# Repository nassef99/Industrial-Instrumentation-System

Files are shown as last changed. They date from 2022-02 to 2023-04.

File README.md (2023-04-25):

# Industrial_Instrumentation_System
ECEN 403/404 Team 45's Senior Design Project (Fall 2021-Spring 2022)

Folders are organized by subsytem/componenents of the overall project.

# NOTE
This repository was cloned from a GitHub Enterprise instance belonging to Texas A&M University, in order to preserve the code before it is shut down. This code was not copied or altered, and authorship belongs to Nassef Ameen, Mitchell Taylor, Ross Petersen, and Julio Gonzalez for their contributions to the original repository.

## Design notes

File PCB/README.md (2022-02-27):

# Altium/PCB Files

Link to original repository: https://github.tamu.edu/mitchtay20/AltiumProject

These are all of the files used to create our 6-layer PCB design in Altium.

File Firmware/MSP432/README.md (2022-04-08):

# Firmware
Firmware for both the MSP432 and ESP32 is found here:

The MSP432 is the microcontroller unit used for this project. It is used to communicate to the sensors/analog to digital converters,
as well as an electronic paper display.

The ESP32 Wifi Module is used to connect the microcontroller unit as well as the cloud databse to facilitate the transfer of data between them. From there this data
can be published to the web application.

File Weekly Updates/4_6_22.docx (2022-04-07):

Julio Gonzalez

- Accomplishments
  - Started Soldering the PCB
- Ongoing Progress
  - Need to figure out how to solder 01005 component onto board
  - Finish integration (soldering) and troubleshoot PCB

Mitchell Taylor

- Accomplishments
  - Finished UART port code
- Ongoing Progress
  - Finish analog to digital code

Nassef Ameen

- Accomplishments
  - Electronic Paper Display code is integrated with rest of firmware
- Ongoing Progress
  - Working on finishing MCU firmware w/Mitchell
  - Helping with ESP32 integration to database (Ross)

Ross Petersen

- Accomplishments
  - Created a serial connection for the ESP32
- Ongoing Progress
  - Finishing ESP32 firmware

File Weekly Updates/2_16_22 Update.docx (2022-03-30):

Julio Gonzalez

- Accomplishment
  - Replaced components that didn’t meet specifications
- Ongoing
  - Order all the parts to populate the PCB
  - Send PCB files for manufacturing

Mitchell Taylor

- Accomplishments
  - Rerouted new components needed for replacement
  - Redid the naming convention for the parts
- Ongoing Progress
  - Getting code done forf MCU

Nassef Ameen

- Accomplishments
  - No progress made on subsystem while PCB design is finalized and order is placed.
- Ongoing Progress
  - Starting code for MSP432 w/Mitchell in preparation for receiving board.
  - Also assisting with code for ESP32 to test integration with wifi module to database

Ross Petersen

- Accomplishments
  - Fixed power routing
  - Figured out what was causing most PCB errors
  - Picked up esp32 test board to test code
- Ongoing Progress
  - Work on esp32 code
  - Finish adding final components to PCB
  - Order PCB

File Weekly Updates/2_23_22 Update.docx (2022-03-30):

Julio Gonzalez

- Accomplishment
  - No major accomplishments personally
  - Sent PCB files to manufacturer (Mitchell)
- Ongoing
  - Purchase all components to populate PCB

Mitchell Taylor

- Accomplishments
  - Got all design files to manufacturer and got feedback from them.
- Ongoing Progress
  - Fixing issues that put the PCB on hold as well as write code skeleton.

Nassef Ameen

- Accomplishments
  - No major accomplishments, planning to make substantial progress by the end of the week
- Ongoing Progress
  - Looking at code for ESP32, as well as MSP432 for Wifi module to database and Microcontroller Unit to database/e-paper display.

Ross Petersen

- Accomplishments
  - Board ordered, fixed manufacturer specifications
- Ongoing Progress
  - Working on esp32 code
  - Plan to test code

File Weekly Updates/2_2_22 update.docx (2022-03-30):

Julio Gonzalez:

- Accomplishments:
  - Finalized Dual Flow Meter schematic on Altium
  - Troubleshooted Flow Meter circuit and obtained a proper pulse output
- Current Goals:
- Finalize 24V Converter schematic
- Integrate Flow Meter and 24V Converter to overall PCB design

Mitchell Taylor:

- Accomplishment:
  - Re-routed MCU, Duel Flow meter, ect.
  - Updated schematics for clarity
  - Condensed the PCB components significantly
  - Connected all individual sub systems together on PCB
- Current Goals:
  - Finalize the design
  - Get github working
  - Get the PCB ordered

Nassef Ameen

- Accomplishments this past week:
  - Set up Altium to help oversee final PCB design changes
  - Helped set up project GitHub repository for project files
- Current Goals:
  - Help finish PCB design so we can order ASAP
  - Get ready to code MCU/E-paper display while board is coming in

Ross Petersen

- Accomplishments
  - Created and presented firstbi-weekly status update
  - Confirmed web interface still connects with database
  - Set up github for PCB files
- Current Goals
  - Add all PCB files to github
  - Finish routing ground and power in PCB design
  - Validate PCB design
  - Order PCB
  - Start preparing code for ESP32

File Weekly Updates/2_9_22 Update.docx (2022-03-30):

Julio Gonzalez:

- Accomplishments:
  - Completed 24V converter schematic
  - Integrated flowmeter and 24V converter schematics (with help of Ross)
- Current Goals:
  - Go through and review the components, swap out components.
  - Order parts for soldering the PCB

Mitchell Taylor:

- Accomplishments:
  - Finished up some routing on PCB, set up git hub for clarity.
- Current Goals:
  - Work on code for MCU and communicate to manufacturers.

Nassef Ameen

- Accomplishments:
  - Helped finish PCB design, double checking routine and component connections and troubleshooting errors
- Current Goals:
  - Prepare to code MCU, and look into that as well as integrating e-paper display
  - Look into testing integration with the database and MCU/ESP32

Ross Petersen

- Accomplishments:
  - Routed all power and ground nets on PCB
  - Finished routing all Flowmeter and MCU nets
  - Completely implemented and routed 24V Converter on PCB
- Current Goals:
  - Order PCB
  - Start coding for ESP32

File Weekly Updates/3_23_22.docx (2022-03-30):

Julio Gonzalez

- Accomplishments
  - Replaced a header footprint on Altium PCB Design with Ross
  - Obtained all PCB parts in-hand
- Ongoing Progress
  - Will pick up 4-20mA simulators from lusher today
  - Waiting for PCB to arrive (ETA Tuesday)

Mitchell Taylor

- Accomplishments
  - Worked on alanlog understanding
- Ongoing Progress
  - Working on MCU firmware

Nassef Ameen

- Accomplishments
  - Obtained examples on use of MSP432 Analog peripherals (eg. ADC14)
- Ongoing Progress
  - Working on MCU firmware

Ross Petersen

- Accomplishments
  - Fixed issues with manufacturer files (again)
  - Moved MCU to top layer, fixed footprint of headers and fixed their routing with Julio
- Ongoing Progress
  - Working on ESP32 firmware

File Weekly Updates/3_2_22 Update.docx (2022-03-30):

Julio Gonzalez

- Accomplishments
  - Swapped components that were out of stock on Mouser / DigiKey
  - Ordered all components to populate pcb
- Ongoing Progress
  - Waiting on PCB and parts to get here so we can start soldering
  - Need to get with sponsor (Dr. Lusher) to get sensors for subsystem

Mitchell Taylor

- Accomplishments
  - Completed routed spare components and began coding some basic outlines.
- Ongoing Progress
  - Complete some basic code and test with launchpad

Nassef Ameen

- Accomplishments
  - Created code outline for MSP432 with Mitchell which code will be built off of, and then integrated with the Electronic Paper Display code I’ve already written.
- Ongoing Progress
  - Begun testing ESP32 WiFi module integration w/database with Ross.

Ross Petersen

- Accomplishments
  - Helped Julio find replacements for out of stock components
  - Developed Gerber files and created order on JLCPCB
- Ongoing Progress
  - Developing the first code for the ESP32
  - Will conduct tests using ESP32 dev board

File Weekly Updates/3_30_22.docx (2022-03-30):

Julio Gonzalez

- Accomplishments
  - Picked up 4-20mA simulators from lusher
  - Received PCB in-hand
- Ongoing Progress
  - Currently soldering PCB board
  - Need to figure out how to solder 01005 component onto board

Mitchell Taylor

- Accomplishments
  - No major accomplishment
- Ongoing Progress
  - Working on code for MCU

Nassef Ameen

- Accomplishments
- Ongoing Progress
  - Working on MCU firmware
  - Helping with ESP32 integration to database
  - Updating Electronic Paper Display code to use serial communication

Ross Petersen

- Accomplishments
  - Created a serial connection for the ESP32
- Ongoing Progress
  - Finishing ESP32 firmware

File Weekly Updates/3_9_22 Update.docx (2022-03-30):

Julio Gonzalez

- Accomplishments
  - Made an appointment to obtain 4-20mA simulators from sponsor (Dr. Lusher)
- Ongoing Progress
  - Need to replace a header footprint on Altium PCB Design

Mitchell Taylor

- Accomplishments
  - Set up SDK files and looked through examples
- Ongoing Progress
  - Continued on MCU firmware

Nassef Ameen

- Accomplishments
  - Obtained example SDK code for MSP432
- Ongoing Progress
  - Working on MSP432 firmware
  - Helping with ESP32 firmware

Ross Petersen

- Accomplishments
  - Created board outline
  - Finished creating Gerber and NC Drill files
  - Fixed manufacturer issues with board
- Ongoing Progress
  - Coding ESP32
  - Testing ESP32 using development board
  - Learning how to solder

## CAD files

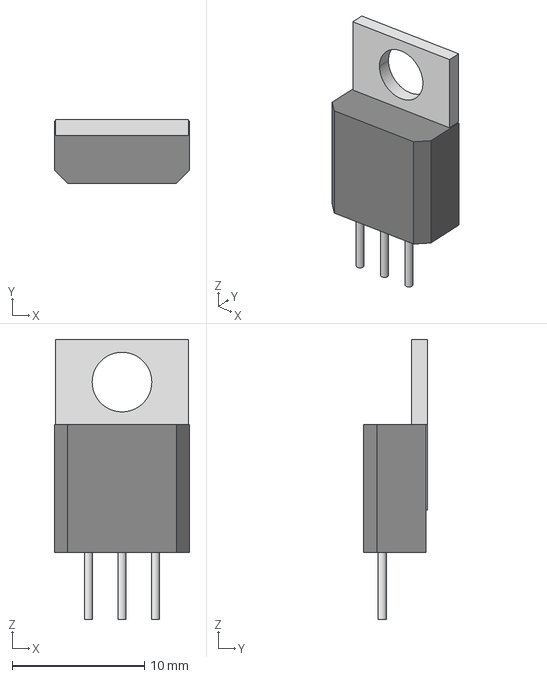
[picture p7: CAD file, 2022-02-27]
PCB/libraray packages/AltiumDesigner/2021-11-06_20-40-10/TO_0S-M34W_VIS.step
10.3 x 4.83 x 21.2 mm

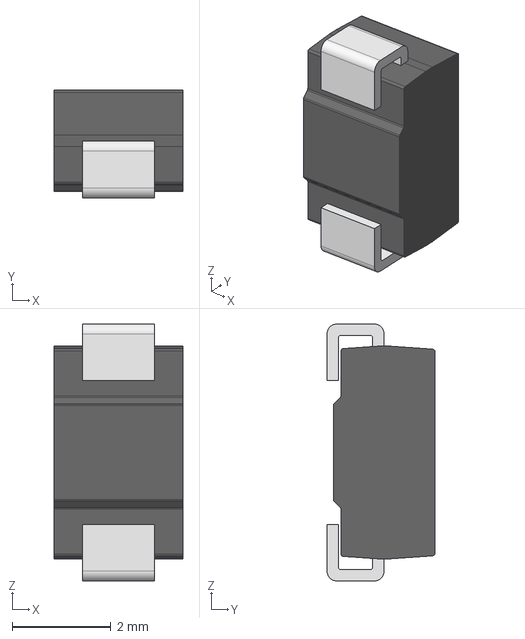
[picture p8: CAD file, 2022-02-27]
PCB/libraray packages/Diode_121613041-659-b340a-13-f/b340a-13-f.stp
2.61 x 2.18 x 5.20 mm

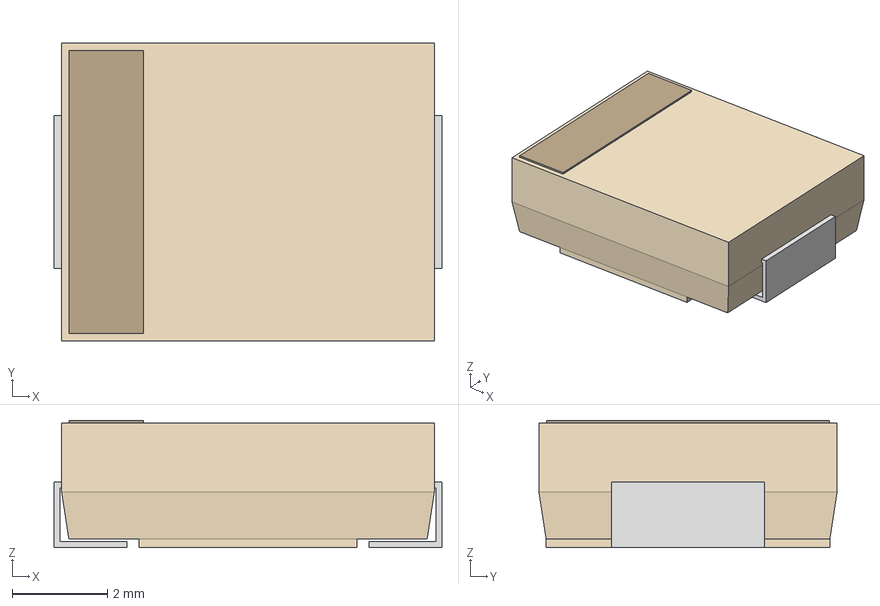
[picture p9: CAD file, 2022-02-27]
PCB/libraray packages/Diode_SS34-E3-9AT/AltiumDesigner/2021-11-04_22-25-46/CR_39AT_VIS.step
8.13 x 6.25 x 2.67 mm

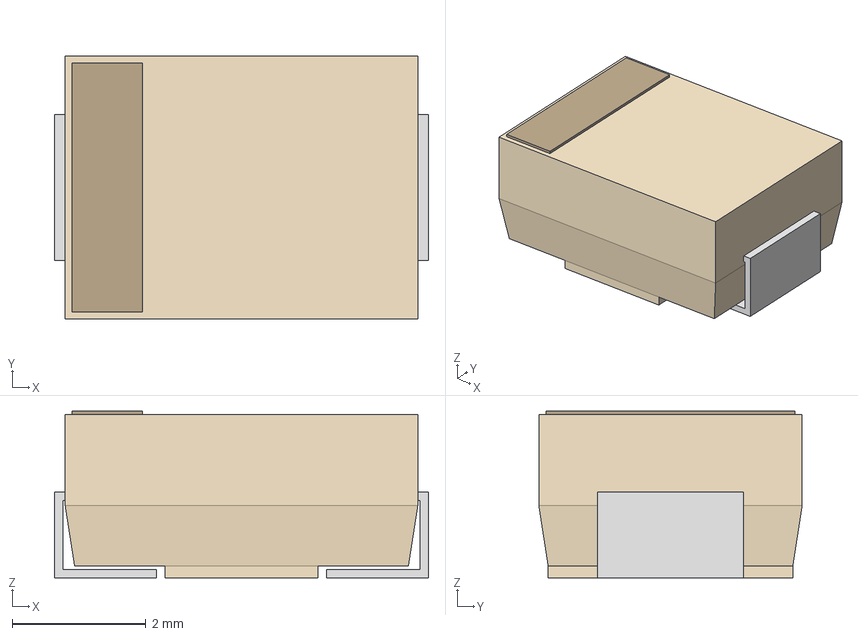
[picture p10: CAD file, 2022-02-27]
PCB/libraray packages/Diode_TVS_1KSMB39CA/AltiumDesigner/2021-11-02_00-22-38/1KSMBSeries_LTF.step
5.59 x 3.94 x 2.49 mm

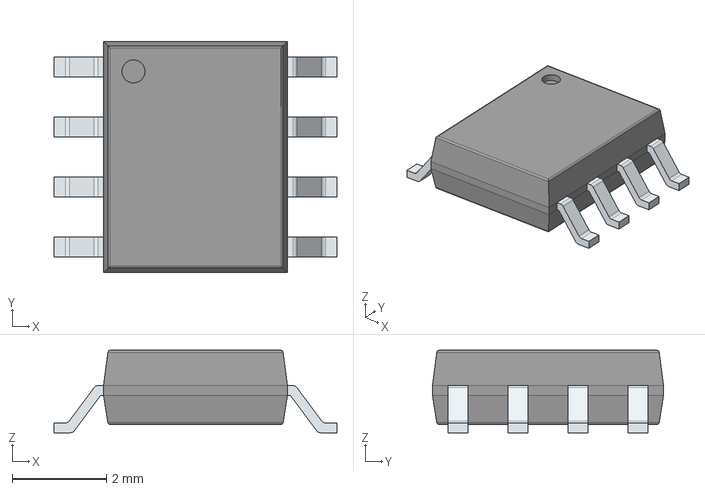
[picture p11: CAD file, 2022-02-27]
PCB/libraray packages/IC_FDS5670/FDS5670/3D/FDS5670.stp
6.00 x 4.90 x 1.75 mm
PinsArrayLR

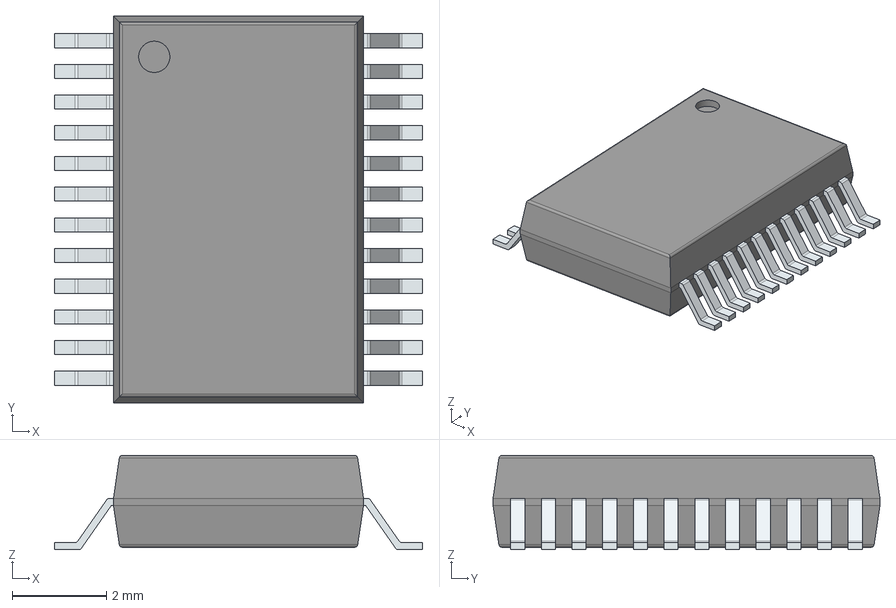
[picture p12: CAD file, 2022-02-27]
PCB/libraray packages/IC_LTC3780EG#PBF/LTC3780EG#PBF/3D/LTC3780EG#PBF.stp
7.80 x 8.20 x 2.00 mm
PinsArrayLR

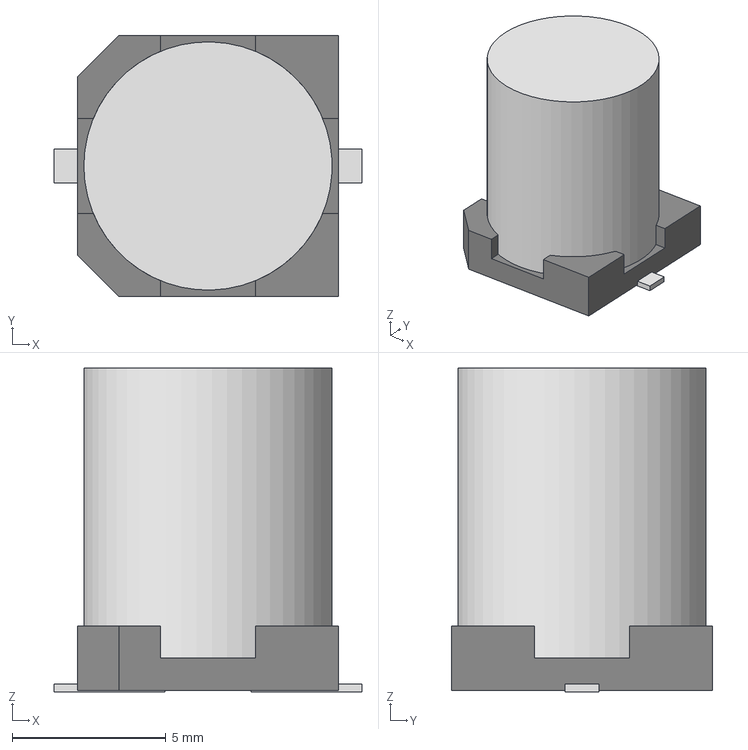
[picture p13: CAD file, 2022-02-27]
PCB/libraray packages/ul_EXV476M016A9GAA/AltiumDesigner/2021-11-02_01-17-10/EXV-9M_KEM.step
10.0 x 8.51 x 10.5 mm

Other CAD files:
PCB/libraray packages/u5/AltiumDesigner/2021-11-06_20-41-46/TO_0S-M34W_VIS.step
PCB/libraray packages/u5/AltiumDesigner/2021-11-06_20-42-54/TO_0S-M34W_VIS.step
PCB/libraray packages/IC_FDS5670/FDS5670/3D/FDS5670.stl
PCB/libraray packages/IC_FDS5670/FDS5670/Allegro/soic127p600x175-8n.psm
PCB/libraray packages/IC_FDS5670/FDS5670/DEHDL/fds5670/chips/chips.prt
PCB/libraray packages/IC_LTC3780EG#PBF/LTC3780EG#PBF/3D/LTC3780EG#PBF.stl
PCB/libraray packages/IC_LTC3780EG#PBF/LTC3780EG#PBF/Allegro/sop65p780x200-24n.psm
PCB/libraray packages/IC_LTC3780EG#PBF/LTC3780EG#PBF/DEHDL/ltc3780eg#pbf/chips/chips.prt

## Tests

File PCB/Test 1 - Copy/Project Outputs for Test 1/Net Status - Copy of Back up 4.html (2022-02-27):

Altium customize

# Net Status Report

Date: | | 2/10/2022
Time: | | 11:39:49 PM
Elapsed Time: | | 00:00:00
Filename: | | C:\Users\Nassef\Documents\ECEN403\AltiumProject\Copy of Back up 4.PcbDoc
Units: | | mmmils

Nets | Layer | Length
24V0 | Signal Layers Only | 0mils
3V3 | Signal Layers Only | 3292.586mils
A5V0 | Signal Layers Only | 4633.919mils
DCORE | Signal Layers Only | 366.992mils
ESP32_BOOT | Signal Layers Only | 522.316mils
ESP32_EN | Signal Layers Only | 539.227mils
ESP32_UART0.RX | Signal Layers Only | 244.498mils
ESP32_UART0.TX | Signal Layers Only | 371.405mils
GND | Signal Layers Only | 30645.723mils
NetC11_1 | Signal Layers Only | 384.234mils
NetC2_1 | Signal Layers Only | 3399.81mils
NetC35_U_Dual_Flowmeter1_1 | Signal Layers Only | 189.023mils
NetC35_U_Dual_Flowmeter1_2 | Signal Layers Only | 101.717mils
NetC35_U_Dual_Flowmeter2_1 | Signal Layers Only | 221.008mils
NetC35_U_Dual_Flowmeter2_2 | Signal Layers Only | 101.717mils
NetC36_U_Dual_Flowmeter1_1 | Signal Layers Only | 129.915mils
NetC36_U_Dual_Flowmeter1_2 | Signal Layers Only | 308.492mils
NetC36_U_Dual_Flowmeter2_1 | Signal Layers Only | 107.733mils
NetC36_U_Dual_Flowmeter2_2 | Signal Layers Only | 196.976mils
NetC37_U_Dual_Flowmeter1_1 | Signal Layers Only | 236.91mils
NetC37_U_Dual_Flowmeter2_1 | Signal Layers Only | 206.513mils
NetC38_U_Dual_Flowmeter1_1 | Signal Layers Only | 104.646mils
NetC38_U_Dual_Flowmeter2_1 | Signal Layers Only | 109.291mils
NetC39_U_Dual_Flowmeter1_1 | Signal Layers Only | 262.669mils
NetC39_U_Dual_Flowmeter2_1 | Signal Layers Only | 632.714mils
NetC40_U_Dual_Flowmeter1_1 | Signal Layers Only | 152.071mils
NetC40_U_Dual_Flowmeter2_1 | Signal Layers Only | 144.773mils
NetC44_2 | Signal Layers Only | 1131.246mils
NetC45_1 | Signal Layers Only | 388.811mils
NetC46_1 | Signal Layers Only | 2241.888mils
NetC46_2 | Signal Layers Only | 4474.449mils
NetC47_1 | Signal Layers Only | 1007.087mils
NetC47_2 | Signal Layers Only | 576.491mils
NetC48_1 | Signal Layers Only | 3453.836mils
NetC48_2 | Signal Layers Only | 2399.189mils
NetC49_1 | Signal Layers Only | 343.383mils
NetC51_1 | Signal Layers Only | 741.545mils
NetCA1_2 | Signal Layers Only | 1931.259mils
NetCA5_2 | Signal Layers Only | 545.708mils
NetCA6_2 | Signal Layers Only | 544.373mils
NetCF3_U_4-20mA1_1 | Signal Layers Only | 932.53mils
NetCF3_U_4-20mA2_1 | Signal Layers Only | 1027.535mils
NetCF3_U_4-20mA3_1 | Signal Layers Only | 1061.659mils
NetCF3_U_4-20mA4_1 | Signal Layers Only | 2864.624mils
NetCF3_U_4-20mA5_1 | Signal Layers Only | 2210.959mils
NetCF3_U_4-20mA6_1 | Signal Layers Only | 1560.621mils
NetCH1_2 | Signal Layers Only | 627.319mils
NetCH2_2 | Signal Layers Only | 577.072mils
NetCL1_2 | Signal Layers Only | 463.358mils
NetCL2_2 | Signal Layers Only | 1037.788mils
NetCR7_2 | Signal Layers Only | 1352.483mils
NetCR8_1 | Signal Layers Only | 5048.357mils
NetD1_1 | Signal Layers Only | 1048.042mils
NetD3_1 | Signal Layers Only | 1385.29mils
NetF1_U_4-20mA1_1 | Signal Layers Only | 622.46mils
NetF1_U_4-20mA2_1 | Signal Layers Only | 181.278mils
NetF1_U_4-20mA3_1 | Signal Layers Only | 344.672mils
NetF1_U_4-20mA4_1 | Signal Layers Only | 1513.751mils
NetF1_U_4-20mA5_1 | Signal Layers Only | 1202.232mils
NetF1_U_4-20mA6_1 | Signal Layers Only | 929.688mils
NetIC6_1 | Signal Layers Only | 0mils
NetIC6_10 | Signal Layers Only | 387.016mils
NetIC6_14 | Signal Layers Only | 970.025mils
NetIC6_16 | Signal Layers Only | 852.801mils
NetIC6_18 | Signal Layers Only | 1046.785mils
NetIC6_23 | Signal Layers Only | 894.309mils
NetIC6_5 | Signal Layers Only | 735.532mils
NetIC6_6 | Signal Layers Only | 1215.141mils
NetJ10_1 | Signal Layers Only | 819.411mils
NetJ8_1 | Signal Layers Only | 300.576mils
NetJ8_2 | Signal Layers Only | 318.841mils
NetJEPD1_11 | Signal Layers Only | 2516.805mils
NetJEPD1_13 | Signal Layers Only | 861.698mils
NetJEPD1_15 | Signal Layers Only | 711.358mils
NetJEPD1_17 | Signal Layers Only | 2206.639mils
NetJEPD1_19 | Signal Layers Only | 1823.807mils
NetJEPD1_23 | Signal Layers Only | 502.883mils
NetJEPD1_25 | Signal Layers Only | 493.758mils
NetJEPD1_29 | Signal Layers Only | 550.762mils
NetJEPD1_31 | Signal Layers Only | 634.03mils
NetJEPD1_33 | Signal Layers Only | 725.876mils
NetJEPD1_34 | Signal Layers Only | 1811.358mils
NetJEPD1_36 | Signal Layers Only | 1634.625mils
NetJEPD1_38 | Signal Layers Only | 1427.104mils
NetR16_U_Dual_Flowmeter1_2 | Signal Layers Only | 612.631mils
NetR16_U_Dual_Flowmeter2_2 | Signal Layers Only | 654.334mils
NetR17_U_Dual_Flowmeter1_2 | Signal Layers Only | 3067.082mils
NetR17_U_Dual_Flowmeter2_2 | Signal Layers Only | 3597.474mils
NetR26_U_Dual_Flowmeter1_1 | Signal Layers Only | 1432.292mils
NetR26_U_Dual_Flowmeter2_1 | Signal Layers Only | 929.784mils
NetR27_U_Dual_Flowmeter1_1 | Signal Layers Only | 4148.567mils
NetR27_U_Dual_Flowmeter2_1 | Signal Layers Only | 4490.982mils
NetR4_1 | Signal Layers Only | 257.848mils
NetR5_1 | Signal Layers Only | 300.674mils
NetRF1_U_4-20mA1_1 | Signal Layers Only | 178.489mils
NetRF1_U_4-20mA2_1 | Signal Layers Only | 193.489mils
NetRF1_U_4-20mA3_1 | Signal Layers Only | 176.307mils
NetRF1_U_4-20mA4_1 | Signal Layers Only | 162.276mils
NetRF1_U_4-20mA5_1 | Signal Layers Only | 165.205mils
NetRF1_U_4-20mA6_1 | Signal Layers Only | 181.307mils
NetSW2_a | Signal Layers Only | 1786.543mils
NetSW3_a | Signal Layers Only | 2250.296mils
NetU1_1 | Signal Layers Only | 0mils
NetU1_100 | Signal Layers Only | 0mils
NetU1_17 | Signal Layers Only | 3062.664mils
NetU1_18 | Signal Layers Only | 2759.143mils
NetU1_19 | Signal Layers Only | 2564.722mils
NetU1_2 | Signal Layers Only | 0mils
NetU1_24 | Signal Layers Only | 0mils
NetU1_25 | Signal Layers Only | 0mils
NetU1_27 | Signal Layers Only | 0mils
NetU1_30 | Signal Layers Only | 0mils
NetU1_46 | Signal Layers Only | 0mils
NetU1_48 | Signal Layers Only | 0mils
NetU1_49 | Signal Layers Only | 0mils
NetU1_50 | Signal Layers Only | 0mils
NetU1_51 | Signal Layers Only | 0mils
NetU1_52 | Signal Layers Only | 0mils
NetU1_53 | Signal Layers Only | 0mils
NetU1_61 | Signal Layers Only | 1533.923mils
NetU1_62 | Signal Layers Only | 1728.202mils
NetU1_63 | Signal Layers Only | 1821.913mils
NetU1_76 | Signal Layers Only | 0mils
NetU1_77 | Signal Layers Only | 0mils
NetU1_88 | Signal Layers Only | 0mils
NetU1_97 | Signal Layers Only | 0mils
NetU1_98 | Signal Layers Only | 3183.501mils
NetU1_99 | Signal Layers Only | 3335.811mils
NetU5_1 | Signal Layers Only | 0mils
NetU5_13 | Signal Layers Only | 243.539mils
NetU5_16 | Signal Layers Only | 0mils
NetU5_18 | Signal Layers Only | 0mils
NetU5_2 | Signal Layers Only | 0mils
NetU8_1 | Signal Layers Only | 296.693mils
Net_U_1_U_4-20mA1_1 | Signal Layers Only | 1208.329mils
Net_U_1_U_4-20mA1_2 | Signal Layers Only | 1830.97mils
Net_U_1_U_4-20mA2_1 | Signal Layers Only | 1261.306mils
Net_U_1_U_4-20mA2_2 | Signal Layers Only | 1418.318mils
Net_U_1_U_4-20mA3_1 | Signal Layers Only | 1345.41mils
Net_U_1_U_4-20mA3_2 | Signal Layers Only | 2071.167mils
Net_U_1_U_4-20mA4_1 | Signal Layers Only | 1236.21mils
Net_U_1_U_4-20mA4_2 | Signal Layers Only | 2800.196mils
Net_U_1_U_4-20mA5_1 | Signal Layers Only | 1297.124mils
Net_U_1_U_4-20mA5_2 | Signal Layers Only | 2431.313mils
Net_U_1_U_4-20mA6_1 | Signal Layers Only | 1273.963mils
Net_U_1_U_4-20mA6_2 | Signal Layers Only | 2132.701mils
RST | Signal Layers Only | 1657.682mils
TMS_SWDIO | Signal Layers Only | 1432.511mils
VCC | Signal Layers Only | 761.792mils
VCORE | Signal Layers Only | 1534.469mils
VSW | Signal Layers Only | 1254.732mils
Vin | Signal Layers Only | 3311.433mils
\ | Signal Layers Only | 0mils

Back to top

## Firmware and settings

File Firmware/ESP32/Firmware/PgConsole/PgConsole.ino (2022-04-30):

#ifdef ESP8266
#include <ESP8266WiFi.h>
#elif defined(ESP32)
#include <WiFi.h>
#else

// Uncomment line below if you use WiFi shield instead of Ethernet
#define USE_ARDUINO WIFI 1
#define RXD2 16
#define TXD2 17

#ifdef USE_ARDUINO_WIFI
#include <WIFI.h>
#else
#include <Ethernet.h>
#endif

#endif
#include <SimplePgSQL.h>



IPAddress PGIP(18,223,247,30);        // your PostgreSQL server IP

const char ssid[] = "SSID";      //  your network SSID (name)
const char pass[] = "password";      // your network password

const char user[] = "ubuntu";       // your database user
const char password[] = "password";   // your database password
const char dbname[] = "test_database";         // your database name

const byte bufferSize = 60;
//char serialBuffer[bufferSize] = "INSERT INTO flowrate VALUES ('33', '2022-04-26 12:44:40')";
char serialBuffer[bufferSize];
byte bufferIndex = 0;
char EOL = '\n';
bool hasData = false;

#if defined(ESP8266) || defined(USE_ARDUINO_WIFI) || defined(ESP32)
int WiFiStatus;
WiFiClient client;
#else
#define USE_ARDUINO_ETHERNET 1
EthernetClient client;
byte mac[] = {0xDE, 0xAD, 0xBE, 0xEF, 0xFE, 0xED}; // your mac address
byte ip[] = {192, 168, 1, 177};                    // your IP address
#endif

char buffer[1024];
PGconnection conn(&client, 0, 1024, buffer);

void setup(void)
{
    Serial.begin(
#ifdef __AVR__
    9600
#else
    115200
#endif
    );
    Serial2.begin(115200, SERIAL_8N1, 16, 17);
#ifdef USE_ARDUINO_ETHERNET
    Ethernet.begin(mac, ip);
#else
    WiFi.begin((char *)ssid, pass);
#endif
}

#ifndef USE_ARDUINO_ETHERNET
void checkConnection()
{
    int status = WiFi.status();
    if (status != WL_CONNECTED) {
        if (WiFiStatus == WL_CONNECTED) {
            Serial.println("Connection lost");
            WiFiStatus = status;
        }
    }
    else {
        if (WiFiStatus != WL_CONNECTED) {
            Serial.println("Connected");
            WiFiStatus = status;
        }
    }
}

#endif

static PROGMEM const char query_rel[] = "\
SELECT a.attname \"Column\",\
  pg_catalog.format_type(a.atttypid, a.atttypmod) \"Type\",\
  case when a.attnotnull then 'not null ' else 'null' end as \"null\",\
  (SELECT substring(pg_catalog.pg_get_expr(d.adbin, d.adrelid) for 128)\
   FROM pg_catalog.pg_attrdef d\
   WHERE d.adrelid = a.attrelid AND d.adnum = a.attnum AND a.atthasdef) \"Extras\"\
 FROM pg_catalog.pg_attribute a, pg_catalog.pg_class c\
 WHERE a.attrelid = c.oid AND c.relkind = 'r' AND\
 c.relname = %s AND\
 pg_catalog.pg_table_is_visible(c.oid)\
 AND a.attnum > 0 AND NOT a.attisdropped\
    ORDER BY a.attnum";

static PROGMEM const char query_tables[] = "\
SELECT n.nspname as \"Schema\",\
  c.relname as \"Name\",\
  CASE c.relkind WHEN 'r' THEN 'table' WHEN 'v' THEN 'view' WHEN 'm' THEN 'materialized view' WHEN 'i' THEN 'index' WHEN 'S' THEN 'sequence' WHEN 's' THEN 'special' WHEN 'f' THEN 'foreign table' END as \"Type\",\
  pg_catalog.pg_get_userbyid(c.relowner) as \"Owner\"\
 FROM pg_catalog.pg_class c\
     LEFT JOIN pg_catalog.pg_namespace n ON n.oid = c.relnamespace\
 WHERE c.relkind IN ('r','v','m','S','f','')\
      AND n.nspname <> 'pg_catalog'\
      AND n.nspname <> 'information_schema'\
      AND n.nspname !~ '^pg_toast'\
  AND pg_catalog.pg_table_is_visible(c.oid)\
 ORDER BY 1,2";

int pg_status = 0;

void doPg(char queryInput[])
{
    Serial.println("Connecting to database...");
    char *msg;
    int rc;
    if (!pg_status) {
        conn.setDbLogin(PGIP,
            user,
            password,
            dbname,
            "utf8");
        pg_status = 1;
        return;
    }

    if (pg_status == 1) {
        rc = conn.status();
        if (rc == CONNECTION_BAD || rc == CONNECTION_NEEDED) {
            char *c=conn.getMessage();
            if (c) Serial.println(c);
            pg_status = -1;
        }
        else if (rc == CONNECTION_OK) {
            pg_status = 2;
            Serial.println("Connection Ok");
        }
        return;
    }
    if (pg_status == 2) {
        //if (!Serial.available()) return;
        char *inbuf;
        inbuf = queryInput;
//        int n = Serial.readBytesUntil('\n',inbuf,63);
//        while (n > 0) {
//            if (isspace(inbuf[n-1])) n--;
//            else break;
//        }
//        inbuf[n] = 0;
        Serial.print("Sending: ");
        Serial.println(inbuf);

        if (!strcmp(inbuf,"\\d")) {
            if (conn.execute(query_tables, true)) goto error;
            Serial.println("Working...");
            pg_status = 3;
            return;
        }
        if (!strncmp(inbuf,"\\d",2) && isspace(inbuf[2])) {
            char *c=inbuf+3;
            while (*c && isspace(*c)) c++;
            if (!*c) {
                if (conn.execute(query_tables, true)) goto error;
                Serial.println("Working...");
                pg_status = 3;
                return;
            }
            if (conn.executeFormat(true, query_rel, c)) goto error;
            Serial.println("Working...");
            pg_status = 3;
            return;
        }

        if (!strncmp(inbuf,"exit",4)) {
            conn.close();
            Serial.println("Thank you");
            pg_status = -1;
            return;
        }
        if (conn.execute(inbuf)) goto error;
        Serial.println("Working...");
        pg_status = 3;
    }
    if (pg_status == 3) {
        rc=conn.getData();
        int i;
        if (rc < 0) goto error;
        if (!rc) return;
        if (rc & PG_RSTAT_HAVE_COLUMNS) {
            for (i=0; i < conn.nfields(); i++) {
                if (i) Serial.print(" | ");
                Serial.print(conn.getColumn(i));
            }
            Serial.println("\n==========");
        }
        else if (rc & PG_RSTAT_HAVE_ROW) {
            for (i=0; i < conn.nfields(); i++) {
                if (i) Serial.print(" | ");
                msg = conn.getValue(i);
                if (!msg) msg=(char *)"NULL";
                Serial2.write(msg);
            }
            Serial.println();
        }
        else if (rc & PG_RSTAT_HAVE_SUMMARY) {
            Serial.print("Rows affected: ");
            Serial.println(conn.ntuples());
        }
        else if (rc & PG_RSTAT_HAVE_MESSAGE) {
            msg = conn.getMessage();
            if (msg) Serial.println(msg);
        }
        if (rc & PG_RSTAT_READY) {
            pg_status = 2;
            Serial.println("Sending Next Message...");
        }
    }
    return;
error:
    msg = conn.getMessage();
    if (msg) Serial.println(msg);
    else Serial.println("UNKNOWN ERROR");
    if (conn.status() == CONNECTION_BAD) {
        Serial.println("Connection is bad");
        pg_status = -1;
    }
}

void listenForData()
{
  char recievedData;

  while(Serial2.available() > 0 && !hasData){
    recievedData = Serial2.read();

    if (recievedData != EOL){
      serialBuffer[bufferIndex++] = recievedData;
      if (bufferIndex >= bufferSize){
        bufferIndex = bufferSize - 1;
      }
    }
    else
    {
      serialBuffer[bufferIndex] = '\0'; //terminate string
      bufferIndex = 0;
      //hasData = true;
      Serial.print("Input: ");
      Serial.println(serialBuffer);
    }
  }
}


void loop()
{
#ifndef USE_ARDUINO_ETHERNET
    checkConnection();
    if (WiFiStatus == WL_CONNECTED) {
#endif

        listenForData();
        doPg(serialBuffer);
        //Serial.println("Moving on to constraints...");
        //char constraints[] = "SELECT minflowrate FROM constraints";
        //doPg(constraints);
        
#ifndef USE_ARDUINO_ETHERNET
    }
#endif
    delay(500);
}

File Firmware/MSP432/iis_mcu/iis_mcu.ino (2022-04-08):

//SDK
#if defined(ENERGIA) // LaunchPad specific
#include "Energia.h"
#else // Arduino general
#include "Arduino.h"
#endif

//Include application, user, and local libraries
#include "SPI.h"
#include "msp.h"
#include "stdio.h"
#include "PDLS_EXT3_Basic.h"

//Define structure
Screen_EPD_EXT3 myScreen(eScreen_EPD_EXT3_417, boardLaunchPad);

void wait(uint8_t second)
{
    for (uint8_t i = second; i > 0; i--)
    {
        Serial.print(formatString(" > %i  \r", i));
        delay(1000);
    }
    Serial.print("         \r");
}

void testDisplay()
{
  uint16_t x, y;
  x = 6;
  y = 6;
  myScreen.selectFont(Font_Terminal8x12);
  
  
  myScreen.gText(x, y, "Industrial Instrumentation System!");
  y += 2 * myScreen.characterSizeY();
  myScreen.gText(x, y, "Latest Flowrate: 10");
  y += 2 * myScreen.characterSizeY();
  myScreen.gText(x, y, "Latest Pressure: 70");
  y += 2 * myScreen.characterSizeY();
  myScreen.gText(x, y, "Latest Temperature: 84.9");

  myScreen.flush();
}

void testShapes()
{
  uint16_t x, y, z, dx, dy, dz;
  x = myScreen.screenSizeX();
  y = myScreen.screenSizeY();
  dx = x / 6;
  dy = y / 6;
  z = min(x, y);
  dz = min(dx, dy);

  //first i
  myScreen.setPenSolid(true);
  myScreen.dRectangle(dx, dy * 2, dx + 1, dy * 3, myColours.red);
  myScreen.circle(dx * 1.5, dy - 1, 30, myColours.red);

  //second i
  myScreen.triangle(dx * 2.5, dy * 5, dx * 3.5, dy * 2, dx * 3.5, dy * 5, myColours.grey);
  myScreen.triangle((dx * 2.5) - 1, dy * 5, dx * 2.5, dy * 2, (dx * 3.5) - 1, dy * 2, myColours.lightRed);
  myScreen.circle(dx * 3, dy - 1, 30, myColours.lightRed);

  myScreen.flush();
}

void displayTitle()
{
  myScreen.selectFont(Font_Terminal12x16);
  myScreen.gText(100, 50, "Team 45 Presents:");
  myScreen.gText(130, 100, "Industrial");
  myScreen.gText(100, 150, "Instrumentation");
  myScreen.gText(150, 200, "System");

  myScreen.flush();
}

void displayFlowrate()
{
  uint16_t x, y;
  x = 6;
  y = 10;
  myScreen.selectFont(Font_Terminal12x16);

  myScreen.gText(x, y, "Latest Flowrate:");
  y += 2 * myScreen.characterSizeY();
  myScreen.gText(x, y, "10 (gallons per second)", myColours.grey);

  y += 4 * myScreen.characterSizeY();
  myScreen.gText(x, y, "Reading occured at:");

  y += 2 * myScreen.characterSizeY();
  myScreen.gText(x, y, "2021 - 11 - 20, 1:30 PM", myColours.grey);

  y += 4 * myScreen.characterSizeY();
  myScreen.gText(x, y, "Time until capacity reached:");

  y += 2 * myScreen.characterSizeY();
  myScreen.gText(x, y, "< 1 minute", myColours.grey);

  myScreen.flush();
}

void displayPressure()
{
  uint16_t x, y;
  x = 6;
  y = 10;
  myScreen.selectFont(Font_Terminal12x16);

  myScreen.gText(x, y, "Latest Pressure:");
  y += 2 * myScreen.characterSizeY();
  myScreen.gText(x, y, "70 (psi)", myColours.grey);

  y += 4 * myScreen.characterSizeY();
  myScreen.gText(x, y, "Reading occured at:");

  y += 2 * myScreen.characterSizeY();
  myScreen.gText(x, y, "2021-11-20, 1:49 PM", myColours.grey);

  y += 4 * myScreen.characterSizeY();
  myScreen.gText(x, y, "WARNING!", myColours.red);

  y += 2 * myScreen.characterSizeY();
  myScreen.gText(x, y, "MAX PRESSURE REACHED!", myColours.red);

  myScreen.flush();
}

void displayTemperature()
{
  uint16_t x, y;
  x = 6;
  y = 10;
  myScreen.selectFont(Font_Terminal12x16);

  myScreen.gText(x, y, "Latest Temperature:");
  y += 2 * myScreen.characterSizeY();
  myScreen.gText(x, y, "84.7 (degrees Fahrenheit)", myColours.grey);

  y += 4 * myScreen.characterSizeY();
  myScreen.gText(x, y, "Reading occured at:");

  y += 2 * myScreen.characterSizeY();
  myScreen.gText(x, y, "2021 - 11 - 20, 1:47 PM", myColours.grey);

  y += 4 * myScreen.characterSizeY();
  myScreen.gText(x, y, "Current Max Temperature:");

  y += 2 * myScreen.characterSizeY();
  myScreen.gText(x, y, "100 (degrees Fahrenheit)", myColours.grey);

  myScreen.flush();
}

//Analog to digital functions
//writeword
//channelselect (6 channels for our design instead of 10)
//look at chip select
//readword


void select_ADC_channel(unsigned char selected_channel, unsigned char *index, unsigned char *sub_channel)
{
    switch(selected_channel)
    {
        case 1:
            *sub_channel = 0x10;
            *index = 1;
            break;

        case 2:
            *sub_channel = 0x10;
            *index = 1;
            break;

        case 3:
            *sub_channel = 0x10;
            *index = 1;
            break;

        case 4:
            *sub_channel = 0x10;
            *index = 1;
            break;

        case 5:
            *sub_channel = 0x10;
            *index = 1;
            break;

        case 6:
            *sub_channel = 0x10;
            *index = 1;
            break;
        default:
        case 0:
            *sub_channel = 0x00;
            *index = 1;
            break;
    }

}

void setup() {
  // put your setup code here, to run once:
  Serial.begin(115200);
  delay(500);
  Serial.println();
  Serial.println("Hello World!");

  //initialize EPD
  Serial.println("Beginning display...");
  myScreen.begin();
  myScreen.setOrientation(7);

  //displaying possible logo
  testShapes();
  myScreen.clear();

  //displaying title card
  //displayTitle();
  //myScreen.clear();

  //wait(2);
  //displaying flowrate reading page
  //displayFlowrate();
  //myScreen.clear();
  
  //displaying pressure reading page
  //displayPressure();
  //myScreen.clear();

  //displaying temperature reading page
  //displayTemperature();
}
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

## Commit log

2022-02-27 added Altium files
    [0.1_Cap_GRM022R60J104ME15L.PcbLib, 0.1_Cap_GRM022R60J104ME15L.SchLib, 0.1uF_Cap_C0805C104M5UACTU.PcbLib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]
2022-04-15 ESP32 added
2022-04-25 Parse and send UART data
2022-04-26 Added newly tested ESP32 code
2022-04-30 Final ESP32 update
2022-05-01 Added uart firmware
